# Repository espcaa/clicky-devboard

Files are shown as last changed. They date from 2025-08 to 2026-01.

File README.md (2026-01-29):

# Clicky devboard

## [[JOURNAL]](https://github.com/espcaa/clicky-devboard/blob/main/JOURNAL.md) - [[BOM]](https://github.com/espcaa/clicky-devboard/blob/main/kicad/production/bom.csv) - [[KICAD FILES]](https://github.com/espcaa/clicky-devboard/tree/main/kicad)

This is a devboard based on the RP2350 chip (the rp2040's successor) with three mechanical switches, with every gpio exposed on pin headers + extras like 3v3 and vbus. It was entirely designed in Kicad and everything is open source! 4 layer board that can be manufactured with normal jlcpcb tolerances.\
\
image (4)
image (2)

## Main components

- RP2350
- 3x Cherry MX switches
- Recommended abracon crystal & inductors
- AP63203WU-7 for the 5v to 3v3 conversion
- 1x23 pin headers
- W25Q64JVSSIQ_C179171 chip for the flash (64mb)
- a usb-c connector

## Features

- clicky
- ~~might work~~ works!
- open source

## Schematic/PCB

 \

you can download everything in the [kicad/ folder](https://github.com/espcaa/clicky-devboard/tree/main/kicad)

## Notes

- there's a resistor missing for the usb-c, so it only works in one orientation :(

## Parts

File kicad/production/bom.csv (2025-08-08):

Designator | Footprint | Quantity | Value | LCSC Part #
C1 | 0805 | 1 | 10uf
C10, C11, C13, C14, C15, C16, C17, C18, C19, C20, C22, C8, C9 | 0402 | 13 | 100n
C2 | 0402 | 1 | 100nf
C23, C24 | 0402 | 2 | 15p
C3, C4 | 0603 | 2 | 22uf
C5, C6, C7 | 0402 | 3 | 4.7u
D1 | 0603 | 1 | LED
J1, J2 | PinHeader_1x23_P2.54mm_Vertical | 2 | Conn_01x23_Pin
L1 | 1210 | 1 | 3.9uh
L2 | 0603-special | 1 | 3.3u | C42411119
R1 | 0402 | 1 | 5.1k
R2, R9 | 0402 | 2 | 33
R3 | 0402 | 1 | 10k
R4, R5 | 0402 | 2 | 1k
R6, R7 | 0402 | 2 | 27
SW1, SW3, SW4 | SW_Cherry_MX_1.00u_Plate | 3 | SW_Push
U1 | TSOT-26_L2.9-W1.6-P0.95-LS2.8-BL | 1 | AP63203WU-7 | C780769
U2 | USB-C-SMD_G-SWITCH_GT-USB-7010ASV | 1 | GT-USB-7010ASV | C2988369
U4 | SOIC-8_L5.3-W5.3-P1.27-LS8.0-BL | 1 | W25Q64JVSSIQ_C179171 | C179171
U5 | CRYSTAL-SMD_4P-L3.2-W2.5-BL | 1 | ABM8-272-T3_C20625731 | C20625731
U6 | QFN-60-1EP_7x7mm_P0.4mm_EP3.4x3.4mm | 1 | RP2350A-QFN60

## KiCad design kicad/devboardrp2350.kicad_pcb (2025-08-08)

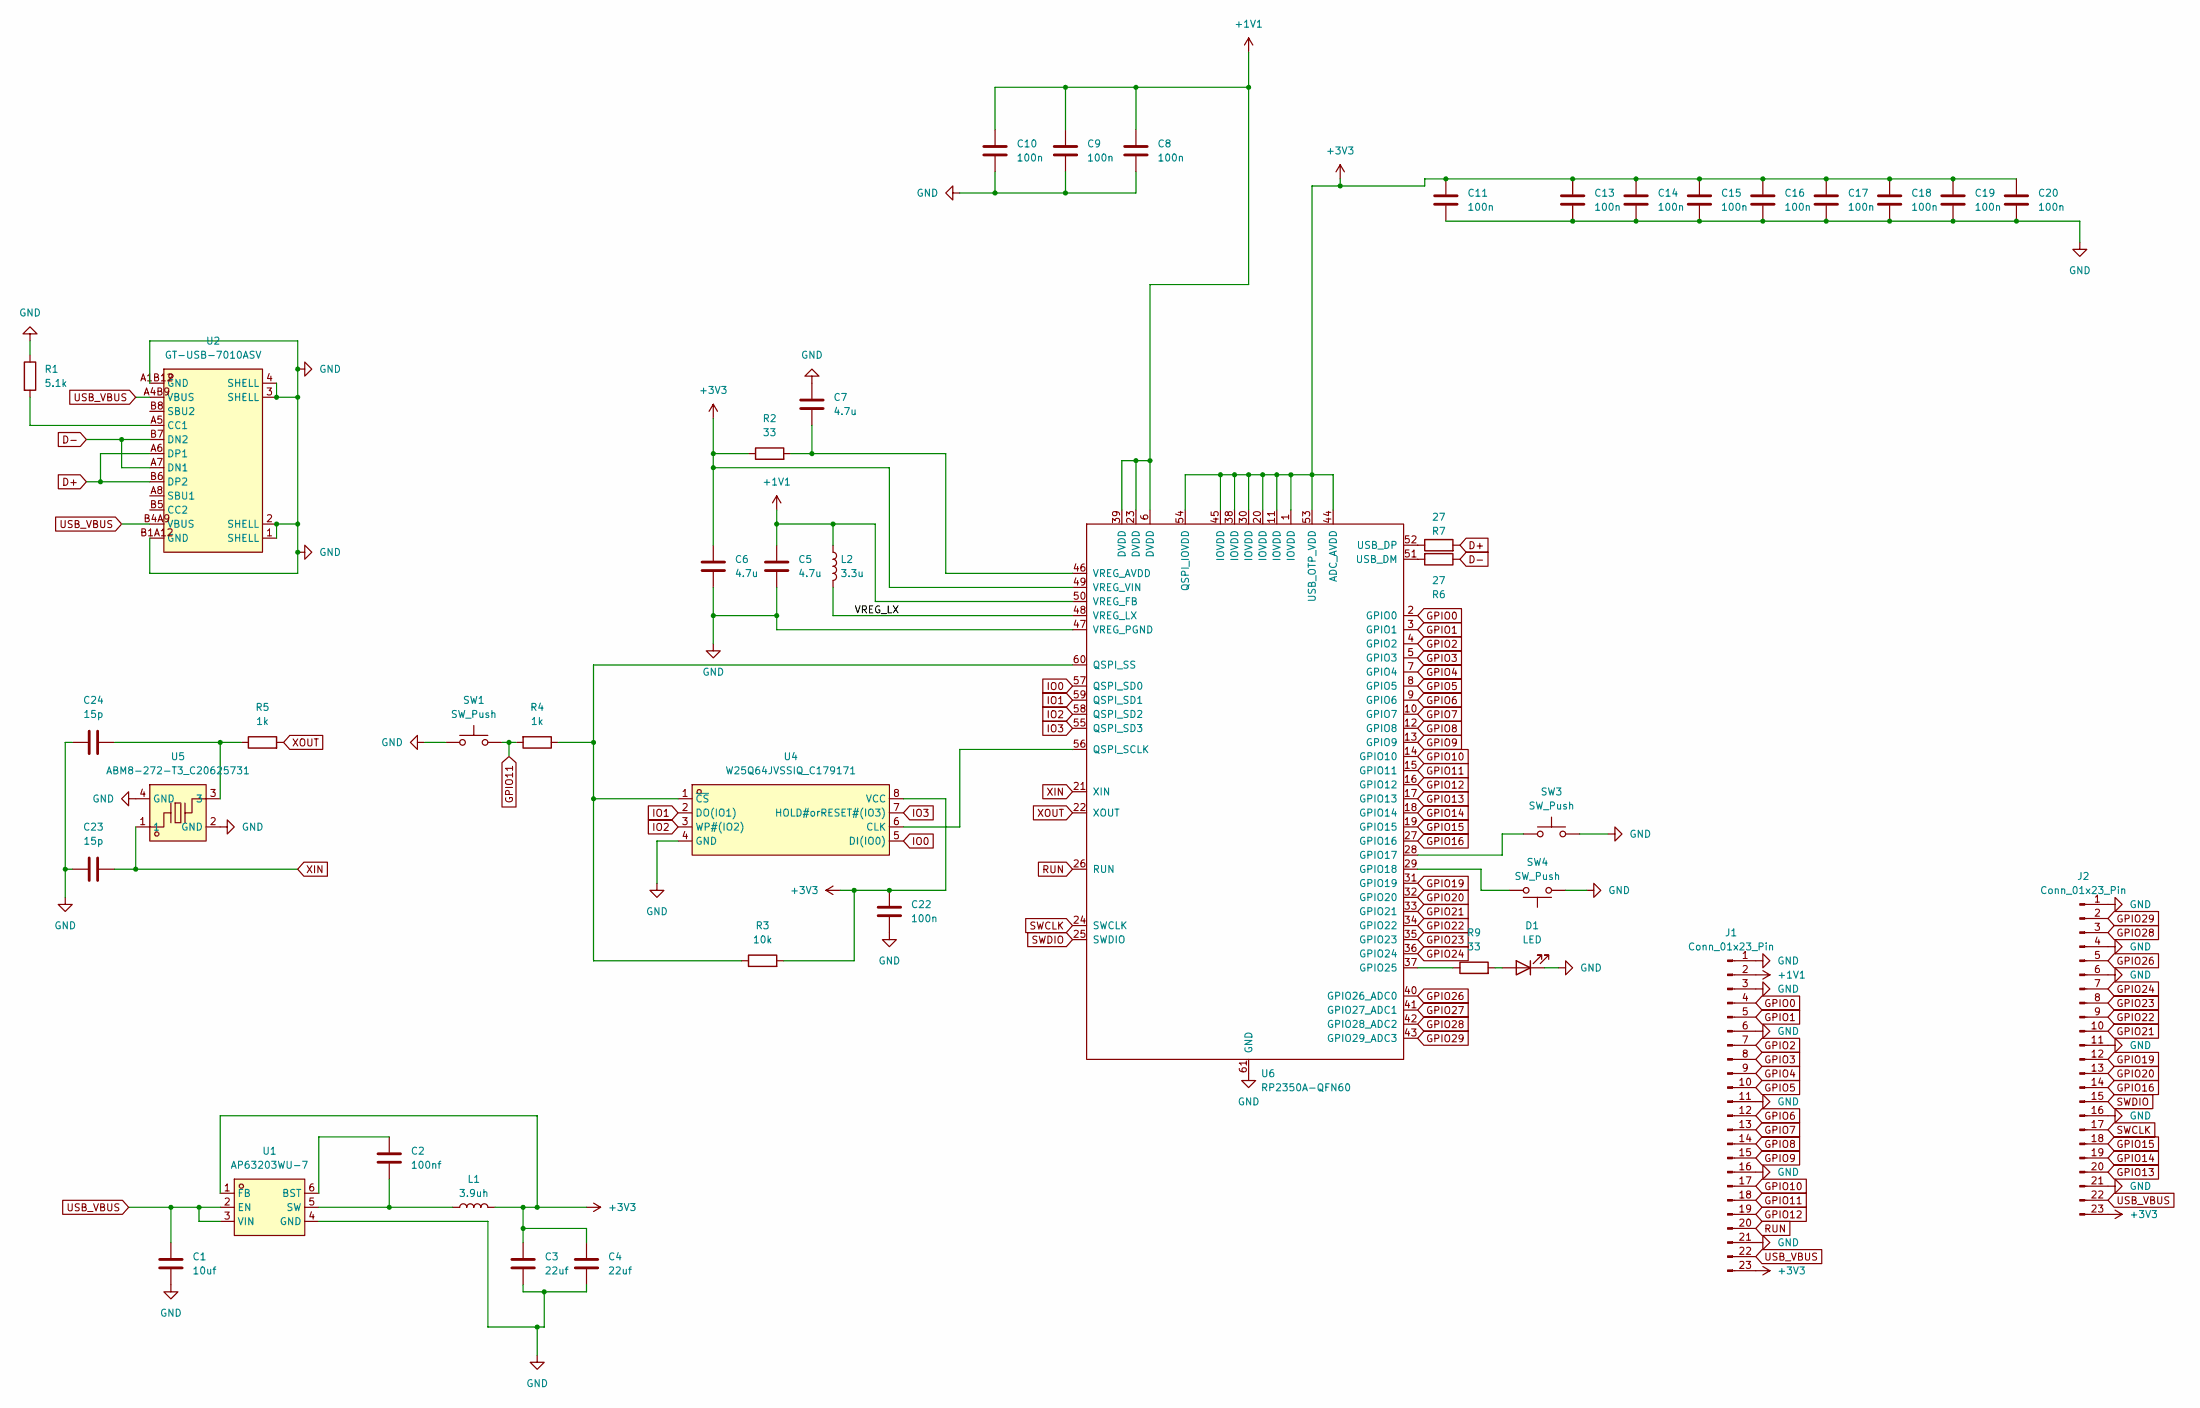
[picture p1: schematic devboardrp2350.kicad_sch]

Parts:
C1: 10uf; C_0805_2012Metric
C2: 100nf; C_0402_1005Metric
C3, C4: 22uf; C_0603_1608Metric
C5, C6, C7: 4.7u; C_0402_1005Metric_small_pads
C8, C9, C10, C11, C13, C14, C15, C16, C17, C18, C19, C20, C22: 100n; C_0402_1005Metric
C23, C24: 15p; C_0402_1005Metric
D1: LED; LED_0603_1608Metric
J1, J2: Conn_01x23_Pin; PinHeader_1x23_P2.54mm_Vertical
L1: 3.9uh; L_1210_3225Metric
L2: 3.3u; 0603-special
R1: 5.1k; R_0402_1005Metric
R2, R9: 33; R_0402_1005Metric
R3: 10k; R_0402_1005Metric
R4, R5: 1k; R_0402_1005Metric
R6, R7: 27; R_0402_1005Metric
SW1, SW3, SW4: SW_Push; SW_Cherry_MX_1.00u_Plate
U1: AP63203WU-7; TSOT-26_L2.9-W1.6-P0.95-LS2.8-BL; LCSC Part C780769
U2: GT-USB-7010ASV; USB-C-SMD_G-SWITCH_GT-USB-7010ASV; LCSC Part C2988369
U4: W25Q64JVSSIQ_C179171; SOIC-8_L5.3-W5.3-P1.27-LS8.0-BL; LCSC Part C179171
U5: ABM8-272-T3_C20625731; CRYSTAL-SMD_4P-L3.2-W2.5-BL; LCSC Part C20625731
U6: RP2350A-QFN60; QFN-60-1EP_7x7mm_P0.4mm_EP3.4x3.4mm

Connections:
+1V1: C5.1, C8.1, C9.1, C10.1, J1.2, L2.1, U6.6 (DVDD), U6.23 (DVDD), U6.39 (DVDD), U6.50 (VREG_FB)
+3V3: C3.1, C4.1, C6.1, C11.1, C13.1, C14.1, C15.1, C16.1, C17.1, C18.1, C19.1, C20.1, C22.1, J1.23, J2.23, L1.2, R2.1, R3.2, U1.1 (FB), U4.8 (VCC), U6.1 (IOVDD), U6.11 (IOVDD), U6.20 (IOVDD), U6.30 (IOVDD), U6.38 (IOVDD), U6.44 (ADC_AVDD), U6.45 (IOVDD), U6.49 (VREG_VIN), U6.53 (USB_OTP_VDD), U6.54 (QSPI_IOVDD)
/VREG_LX: L2.2, U6.48 (VREG_LX)
D+: R7.2, U2.A6 (DP1), U2.B6 (DP2)
D-: R6.1, U2.A7 (DN1), U2.B7 (DN2)
GND: C1.2, C3.2, C4.2, C5.2, C6.2, C7.1, C8.2, C9.2, C10.2, C11.2, C13.2, C14.2, C15.2, C16.2, C17.2, C18.2, C19.2, C20.2, C22.2, C23.1, C24.1, D1.1 (K), J1.1, J1.3, J1.6, J1.11, J1.16, J1.21, J2.1, J2.4, J2.6, J2.11, J2.16, J2.21, R1.1, SW1.1, SW3.2, SW4.1, U1.4 (GND), U2.1 (SHELL), U2.2 (SHELL), U2.3 (SHELL), U2.4 (SHELL), U2.A1B12 (GND), U2.B1A12 (GND), U4.4 (GND), U5.2 (GND), U5.4 (GND), U6.47 (VREG_PGND), U6.61 (GND)
GPIO0: J1.4, U6.2 (GPIO0)
GPIO1: J1.5, U6.3 (GPIO1)
GPIO2: J1.7, U6.4 (GPIO2)
GPIO3: J1.8, U6.5 (GPIO3)
GPIO4: J1.9, U6.7 (GPIO4)
GPIO5: J1.10, U6.8 (GPIO5)
GPIO6: J1.12, U6.9 (GPIO6)
GPIO7: J1.13, U6.10 (GPIO7)
GPIO8: J1.14, U6.12 (GPIO8)
GPIO9: J1.15, U6.13 (GPIO9)
GPIO10: J1.17, U6.14 (GPIO10)
GPIO11: J1.18, R4.2, SW1.2, U6.15 (GPIO11)
GPIO12: J1.19, U6.16 (GPIO12)
GPIO13: J2.20, U6.17 (GPIO13)
GPIO14: J2.19, U6.18 (GPIO14)
GPIO15: J2.18, U6.19 (GPIO15)
GPIO16: J2.14, U6.27 (GPIO16)
GPIO19: J2.12, U6.31 (GPIO19)
GPIO20: J2.13, U6.32 (GPIO20)
GPIO21: J2.10, U6.33 (GPIO21)
GPIO22: J2.9, U6.34 (GPIO22)
GPIO23: J2.8, U6.35 (GPIO23)
GPIO24: J2.7, U6.36 (GPIO24)
GPIO26: J2.5, U6.40 (GPIO26_ADC0)
GPIO27: U6.41 (GPIO27_ADC1)
GPIO28: J2.3, U6.42 (GPIO28_ADC2)
GPIO29: J2.2, U6.43 (GPIO29_ADC3)
IO0: U4.5 (DI(IO0)), U6.57 (QSPI_SD0)
IO1: U4.2 (DO(IO1)), U6.59 (QSPI_SD1)
IO2: U4.3 (WP#(IO2)), U6.58 (QSPI_SD2)
IO3: U4.7 (HOLD#orRESET#(IO3)), U6.55 (QSPI_SD3)
unnamed: C24.2, R5.1, U5.3
unnamed: D1.2 (A), R9.2
unnamed: C2.1, U1.6 (BST)
unnamed: C2.2, L1.1, U1.5 (SW)
unnamed: R1.2, U2.A5 (CC1)
unnamed: U4.6 (CLK), U6.56 (QSPI_SCLK)
unnamed: R3.1, R4.1, U4.1 (~CS), U6.60 (QSPI_SS)
unnamed: SW3.1, U6.28 (GPIO17)
unnamed: SW4.2, U6.29 (GPIO18)
unnamed: R9.1, U6.37 (GPIO25)
unnamed: R6.2, U6.51 (USB_DM)
unnamed: R7.1, U6.52 (USB_DP)
unnamed: C7.2, R2.2, U6.46 (VREG_AVDD)
RUN: J1.20, U6.26 (RUN)
SWCLK: J2.17, U6.24 (SWCLK)
SWDIO: J2.15, U6.25 (SWDIO)
USB_VBUS: C1.1, J1.22, J2.22, U1.2 (EN), U1.3 (VIN), U2.A4B9 (VBUS), U2.B4A9 (VBUS)
XIN: C23.2, U5.1, U6.21 (XIN)
XOUT: R5.2, U6.22 (XOUT)

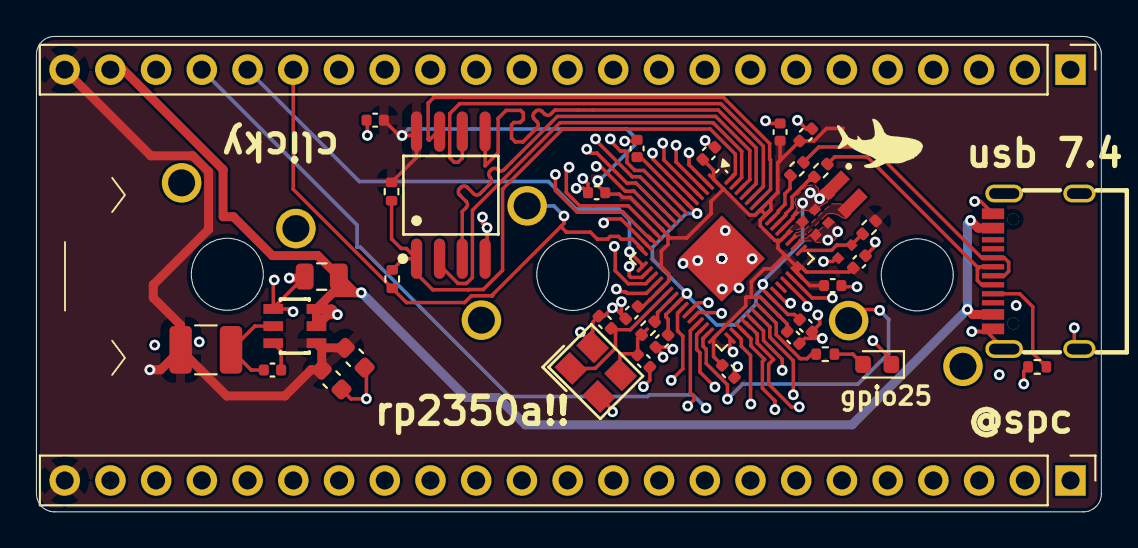
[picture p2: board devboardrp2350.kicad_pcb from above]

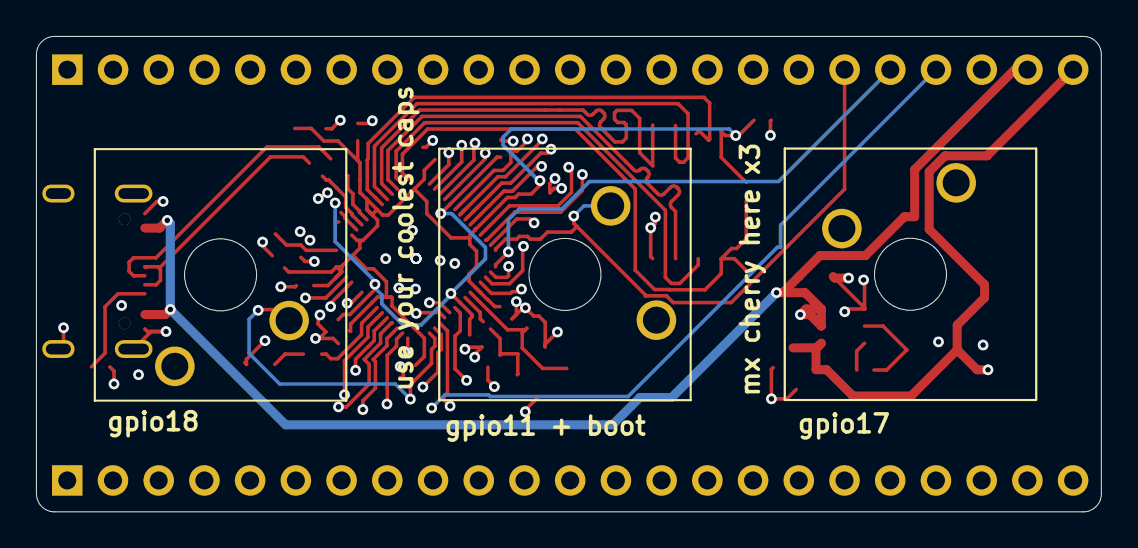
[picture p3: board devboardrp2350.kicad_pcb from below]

Board: 4 copper layers, 59.2 x 26.4 mm, 43 parts (3 on the bottom side), 55 nets.

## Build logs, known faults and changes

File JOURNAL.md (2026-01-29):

---
Title: "Clicky devboard"
Author: "@espcaa"
Description: "a rp2350 based devboard with mechanical switches :D"
Created On: "2/08/2025"
---

# August 1st-2nd, 2025 (we like working at midnight pf)

I got most of the schematic done! I just need to figure out what type of io i'll use (uh probably just pin headers?) and i'll be done!!!! \
Now comes the routing.... aaaaa



**Total time spent: 2h30**

# August 2nd, 2025 (Part II)

I attributed all of the footprints to the symbols after some research and converted my board to a pcb!
I spent a good hour trying to debugging why i couldn't see the GND net when trying to make a plane (even cyao told me it was over :sob:) but i finally found it was because of another net connected to the GND that renamed it!



I also changed the symbol from the easyeda one to the official one for more legibility + added headers to expose the gpios! \



**Time spent: 3h, Total time spent: 5h30**

# August 2nd, 2025 (Part III) & August 3rd, 2025

I grinded with tongyu and kailing on my board during the night and after a lot, a lot and a lot of errors, crashouts i managed to fully route my board!
It looks very cool and comes at under 100$/5 units!!!
I learned so much about kicad, and that's very cool!



**Time spent: 9h, Total time spent: 14h30**

# August 5-6th

After realizing my pcb was quite bad (bad crystal routing and uh a lot of other things that rudy pointed at) + the fact that it wasn't "clicky", i decided to re route it!
I spent a lot of time on it but it's cleaner, HAS 0 DRC ISSUES!!!! (i'm so proud of that one :sob:) + it looks waay cooler!!!
I also updated to a 4 layer board with this stackup:
- 1st layer : 3v3
- 2nd layer : GND
- 3nd layer : gpio, slow signals
- 4nd layer : vbus + random things





**Time spent : 5 hours, Total time spent: 19h30**

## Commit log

2025-08-02 first commit!
    [devboardrp2040.kicad_pcb, devboardrp2040.kicad_sch]
2025-08-02 updated the kicad files
    [devboardrp2040.kicad_pcb, devboardrp2040.kicad_sch]
2025-08-07 FINISHED KAUHdiodu
    [bom.csv, designators.csv, devboardrp2040.kicad_pcb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]
2025-08-08 kicad updates
2026-01-29 fixed the confusing naming
    [devbackup.kicad_pcb, devboardrp2350.kicad_pcb, devboardrp2350.kicad_sch]
